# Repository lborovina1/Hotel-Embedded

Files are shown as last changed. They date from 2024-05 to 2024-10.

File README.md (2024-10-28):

# Hotel Management Embedded Systems Project

## Overview
This repository contains the implementation of an embedded systems project focused on developing a hotel management system. The project incorporates several essential components, including RFID programming for hotel room access, servo motor-controlled ramps, a user interface for programming RFID cards, and a gas detection alarm system. This project is part of the **Embedded Systems** course at the **Faculty of Electrical Engineering** at the **University of Sarajevo**.

Team members: Borovina Lamija, Jozić Ivona, Kurtović Esma and Muslić Ismar. </br>
Video demonstration: https://youtu.be/YYLt_LLE6pE </br>

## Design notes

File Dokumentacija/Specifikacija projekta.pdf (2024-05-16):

Specifikacija projekta na kursu Ugradbeni sistemi

Tema projekta: Hotel

Članovi tima: Borovina Lamija

Jozić Ivona

Kurtović Esma

Muslić Ismar

Specifikacija projekta:

U sklopu našeg projekta je planirana implementacija pojedinih funkcionalnosti koje se vežu za funkcioniranje hotela. Zamišljena je implementacija tri konkretne funkcionalnosti, koje se objedinjuju u jednu cjelinu. Planirane funkcionalnosti su:

1) Dodjela RFID kartica kao ključeva za sobe – RFID RC522 čitač i kartice
Ova funkcionalnost je zamišljena na način da se na recepciji hotela vrši povezivanje određene kartice i sobe. Za unošenje broja sobe se namjerava koristiti matrična tastatura, a unos će se prikazati na sedam segmentnom displeju.
Pri ulasku u sobu se očitava kartica, a za signalizaciju validnosti će biti korištene LED diode, pri čemu zelena svjetlost signalizira ispravnost, tj. da se u sobu može ući sa skeniranom karticom, dok crvena svjetlost signalizira neispravnost.
2) Ulazna rampa – servomotor i MQTT protokol komunikacije
Ova funkcionalnost je zamišljena kao simulacija rada parking rampe, koja će u demonstraciji biti predstavljena u vidu makete. Gosti hotela prilikom prijave u hotel dobivaju šifru klijenta za korištenje MQTT aplikacije.
Servomotor služi za podizanje rampe, a rad motora bi bio kontroliran kroz MQTT aplikaciju, te bi se pritiskom na dugme u aplikaciji aktivirao i podizao rampu.
3) Protupožarni alarm – MQ5 senzor i piezoelektrični zvučnik
Korištenjem MQ5 senzora za detekciju zapaljivih plinova je moguće detektovati prisustvo štetnih plinova, odnosno požara, te bi isti bio implementiran na način da prilikom detekcije nestandardnog sastava zraka, pokreće zvuk alarma koji bi bio se oglašavao kroz zvučnik. Ovo će predstavljati svojevrstan protupožarni alarm koji je prisutan u okviru svake hotelske sobe.

Razvojni sistem:

Zamišljeni sistem je planiran za implementaciju na Raspberry Pi Pico mikrokontroleru, s obzirom na dostupni broj pinova, kao i sadržavanje WiFi modula.

Komponente koje će biti korištene:

Naziv komponente:
RFID RC522 čitač
RFID kartice
Matrična tastatura
Četverocifreni sedam segmentni displej LED diode
Servomotor
MQ5 senzor za detekciju zapaljivih plinova Piezoelektrični zvučnik

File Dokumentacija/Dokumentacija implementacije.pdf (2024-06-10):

## Dokumentacija implementacije

Za potrebe projekta korištena su dva mikrokontrolera:

- Raspberry Pi Pico (spojena 2 RFID čitača, matrična tastatura i LCD displej)
- ESP8266 (spojen servomotor za rampu).

Planirane funkcionalnosti smo implementirali na sljedeći način:

1) Uvezivanje kartice s brojem sobe na recepciji
a. Unos broja sobe

Unos se započinje pritiskom na taster button. Za unos broja sobe se koristi matrična tastatura, a prilikom unosa informativne poruke se prikazuju na LCD displeju. Za potrebe obrade unosa se koriste klase Tastatura, pomoću koje se bilježi unos, te TastController, koji sadrži instancu klase Tastatura i vraća odgovarajuće vrijednosti u ovisnosti od validnosti unosa.

Očitavanje unosa s tastature je realizovano na sljedeći način:

- Zasebni redovi (u kodu rows, deklarisani kao digitalni izlazi) se pomoću Timer-a periodično pale. Trenutno aktivni red (sačuvan u varijabli currentRow) se tako mijenja svakih 50ms. Timer se inicijalizira pritiskom na gore navedeni button, u sklopu funkcije ocitaj():

self.timer=Timer(period=50, mode=Timer.PERIODIC, callback=self.rowFun)

- Na pin-ove za kolone (u kodu cols, deklarisane kao digitalni ulazi) su postavljeni hardverski interrupt-i, čija je callback funkcija colPress():

for i in range(4):
self.cols[i].irq(handler = self.colPress, trigger = Pin.IRQ_RISING)
- U okviru iste, nakon debouncing-a, se u varijablu currentCol pohranjuje broj pritisnute kolone.

Zatim se na osnovu vrijednosti currentRow i currentCol određuje pritisnuti taster, te akcija koju je potrebno izvršiti. Kao signalizacija neispravnog unosa ili potvrde se koriste bool varijable pogresanUnos i potvrdjeno. Unos se obrađuje na sljedeći način:

- Za pritisnute tastere 'A', 'B', 'D' i '*' se unos završava deinicijalizacijom timer-a i varijabla pogresanUnos postavlja na True.
- Pritiskom na taster '#' se potvrđuje četverocifreni unos te varijabla potvrdjeno postavlja na True. U slučaju da je '#' pritisnut prije nego što su unesene 4 cifre, unos nije validan te se ponovno pogresanUnos postavlja na True. U oba slučaja se unos završava deinicijalizacijom timer-a.
- Ukoliko je pritisnut taster 'C', briše se posljednji uneseni karakter.
- Tasteri s ciframa od '0' do '9' se smatraju validnim unosom, izuzev u situaciji kada se dotadašnji unos već sastoji od 4 cifre, jer se prelazi maksimalna dozvoljena veličina.

Ukoliko je unos ispravan, cifra se dodaje na string

self.string += self.matrica[self.currentRow][self.currentCol]

koji se ispisuje na displej

self.lcd.clear()
self.lcd.putstr(self.string).

U okviru metode getUnos() klase TastController, a koja se koristi za dobivanje unosa s tastature, se vraćaju odgovarajuće vrijednosti. Povratna vrijednost -1 označava neispravan unos (u slučaju da je pogresanUnos postavljen na True), a uneseni string označava ispravan unos (u slučaju da je potvrdjeno postavljeno na True).

b. Uvezivanje unesene sobe i RFID kartice prislonjene čitaču

Nakon što je završen unos pomoću matrične tastature, mogu nastupiti dva slučaja. Ukoliko je unos neispravan, pomoću LCD displeja se korisniku signalizira greška, te on ima opciju da ponovno započne unos pritiskom na button. U slučaju kada je unos broja sobe ispravan prelazi se na konfiguraciju, tj. uvezivanje unesene sobe s RFID karticom kojom se želi omogućiti ulazak u nju. Najprije se korisniku na displeju ispisuje poruka da RFID čitaču reader1 prinese karticu koja se želi uvezati sa sobom, te se očitava njegovo stanje.

(stat1, tag_type1) = reader1.request(reader1.REQIDL)

Kada se prinese kartica koja se želi konfigurisati, čita se njen ID

(stat, uid) = reader1.SelectTagSN()
card = int.from_bytes(bytes(uid),"little", False)

i u mapi karticeISobe se unesenoj sobi pridružuje vrijednost prislonjene kartice

karticeISobe[int(soba)] = card.

2) Pristup sobi pomoću kartice i RFID čitača

Čitanjem vrijednosti iz mape karticeISobe pri pokušaju ulaska u sobe se vrši provjera da li je dozvoljen pristup prislonjenom karticom. Ova funkcionalnost je demonstrirana pomoću RFID čitača reader2, koji predstavlja čitač za sobu 1000. Naime, nakon što se na recepciji na prethodno opisani način uveže soba 1000 s određenom karticom čiji se ID pohranjuje u mapu, prilikom prislanjanja kartice čitaču reader2, njen ID se poredi s vrijednošću u mapi.

if karticeISobe[1000] == card

Ukoliko su ove vrijednosti jednake, paljenjem zelene LED se signalizira da je kartica ispravna i njom se može pristupiti sobi. U suprotnom, paljenjem crvene LED se signalizira da prislonjena kartica nije povezana sa sobom kojom se pristupa, te ulazak u nju nije moguć.

3) Povezivanje i kontrola parking – rampe

Kontrola parking rampe je implementirana koristeći MQTT komunikacijski protokol. Na uređaju ESP8266 je inicijalizirana konekcija na WiFi koristeći SSID i password lokalne WiFi mreže, nakon čega se MQTT klijent može uspješno povezati na cloud brokera. Istovremeno je na kontrolnom uređaju (Android smartphone) podešena „MQTT Dash“ aplikacija sa podešenim opcijama za sve funkcionalnosti sistema. Moguće je jednim tasterom aktivirati rampu, te imati uvid u trenutno stanje sistema i konekcije, kao i stanje semafora (zeleno i crveno svjetlo).

Pozivom metode

client.subscribe("USprojekat/Servo", [](const String & payload)

podešava se supskripcija na temu „USprojekat/Servo“ koja se koristi za kontrolu servo motora, odnosno same rampe. Sve ostale teme se koriste samo za publishing statusnih poruka o sistemu, tako da za njih nije ni potrebna supskripcija.

Lambda funkcija koja je proslijeđena kao parametar metodi subscribe() se bavi svim funkcijama vezanim za kontroliranje same rampe. U slučaju da je sa korisničke strane na temi registrovana poruka „1“, za aktiviranje rampe, najprije se publish-aju poruke o stanju LED dioda na odgovarajuće teme, a zatim se i podiže sama rampa podešenjem ugla otklona servo motora.

| int pos = 0;
for(pos; pos <= 180; pos += 5) servo.write(pos);

Na isti način se rampa ponovno i spušta nakon čekanja od 10s da bi automobil mogao da prođe. Tim želi naglasiti da je kvalitetnije rješenje implementirati u sklopu rampe i ultrazvučni mjerač udaljenosti ili IR blaster i reciever sa suprotnih strana kako bi sistem „znao“ kada je automobil ispod rampe. Time bi se izbjeglo da rampa udari u automobil u slučaju da za 10s on ne prođe ispod iste. Nažalost, u sklopu ovog projekta nije bilo dovoljno vremena za takvu implementaciju.
Statusne poruke o stanju rampe se pravovremeno šalju na svoje odgovarajuće teme, a također se i na serijski port šalju iste poruke, kako bi se uz pomoć monitora serijske veze uvidjelo funkcioniranje mikrokontrolera i olakšalo eventualno servisiranje, odnosno debugging. Poruke koje se ispisuju su u formatu:

Serial.println("Podizem rampu...");
Serial.println("Rampa podignuta!"); Serial.println("Spustam rampu...");
Serial.println("Rampa spustena.");

Iste statusne poruke se šalju i na odgovarajuće teme metodom publish() kako bi se i na korisničkoj strani mogle vidjeti u okviru MQTT Dash aplikacije.

4) Smoke alarm (MQ5 senzor zapaljivih plinova)

Koristeći MQ5 senzor zapaljivih gasova i aktivni buzzer s radnim naponom od 5V, realiziran je jednostavan alarm za dim, koji svaka hotelska soba posjeduje.

Kompletan sklop je zalemljen na perfboard i odvojen od sistema mikrokontrolera, te tako radi potpuno automatski. S obzirom na to da MQ5 senzor daje logičko 0 na digitalnom izlazu kada je plin detektovan, a logičko 1 onda kada plina nema, potrebno je bilo napraviti inverter signala, što je realizirano uz pomoć dva NPN tranzistora, konkretnije, BC547. Također je paralelno sa digitalnim izlazom i GND spojen kondenzator kapaciteta 470 µF, kako bi se osiguralo da nekonzistentne promjene stanja na digitalnom izlazu (stanja između 0 i 5V) budu zanemarena, te da se tranzistorima baza ispravno otvara. Prvi tranzistor funkcionira kao inverter signala, te je njegov kolektor direktno prespojen sa bazom drugog tranzistora, dok je istom emiter spojen na GND. Tako se osigurava da na bazu drugog tranzistora dovodimo struju samo onda kada je baza prvog tranzistora zatvorena, odnosno kada je na digitalnom izlazu 0V. Drugi tranzistor potom, prilikom otvaranja baze, propušta napon od 5V na aktivni piezoelektrični buzzer.

Detaljna shema spajanja, kao i shema električnog kruga, je data u prilogu.

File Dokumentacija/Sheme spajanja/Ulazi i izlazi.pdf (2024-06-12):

## Ulazi i izlazi

## Raspberry Pi Pico

Digitalni izlazi | Digitalni ulazi
Pin(16, Pin.OUT) (red 1) | Pin(0, Pin.IN, Pin.PULL_DOWN) (button)
Pin(17, Pin.OUT) (red 2) | Pin(20, Pin.IN, Pin.PULL_DOWN) (kol 1)
Pin(18, Pin.OUT) (red 3) | Pin(21, Pin.IN, Pin.PULL_DOWN) (kol 2)
Pin(19, Pin.OUT) (red 4) | Pin(22, Pin.IN, Pin.PULL_DOWN) (kol 3)
Pin(7, Pin.OUT) (crvena LED) | Pin(26, Pin.IN, Pin.PULL_DOWN) (kol 4)
Pin(6, Pin.OUT) (zelena LED)
SPI izlazi | SPI ulazi
sck=Pin(2) (reader1 clock) | miso=Pin(4) (reader1 MISO)
mosi=Pin(3) (reader1 MOSI) | miso=Pin(12) (reader2 MISO)

### cs=Pin(1) (reader1 CS) rst=Pin(5) (reader1 RST) sck=Pin(10) (reader2 clock) mosi=Pin(11) (reader2 MOSI) cs=Pin(9) (reader2 CS) rst=Pin(13) (reader2 RST)

I2C izlazi | I2C ulazi
sda=Pin(14) (I2C data)
scl=Pin(15) (I2C clock)

## ESP8266

## Digitalni izlazi

SERVO (D4) | (kontrola servo motora)
LED_RED (D2) | (crvena LED)
LED_GREEN (D1) | (zelena LED)

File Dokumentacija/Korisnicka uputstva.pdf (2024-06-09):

### Korisnička uputstva

Korištenje sistema projektovanog u sklopu ovog projekta je zapravo veoma jednostavno unatoč njegovom nešto obimnijem sadržaju.

U sklopu sistema postoji nekoliko funkcionalnosti čiji će način korištenja u nastavku biti detaljno objašnjen. Svi potrebni kodovi i biblioteke su već spremljeni na razvojne sisteme, tako da je za pokretanje svih funkcionalnosti neophodno samo priključivanje napajanja na struju korištenjem odgovarajućeg adaptera.

U nastavku uputstva za korištenje svake od funkcionalnosti sadržanih u sklopu projekta:

1) Uvezivanje kartice sa brojem sobe na recepciji

Za pokretanje ovog modula rada potrebno je da pritisnete taster, nakon čega će se na LCD ekranu ispisivati sva uputstva.
Prvo je potrebno da unesete odgovarajući broj sobe korištenjem matrične tastature, gdje se zahtijeva da se unesu 4 cifre. U slučaju da sa tastature unesete karaktere A, B, D ili *, na ekranu će se ispisati poruka o grešci te će biti neophodno da ponovite unos. Karakter C možete koristiti u slučaju greške, za brisanje unosa (jedan pritisak će ukloniti jednu unesenu cifru). Nakon što unesete 4 cifre, trebate pritisnuti karakter # na matričnoj tastaturi kako bi vaš unos bio potvrđen.
Na LCD ekranu će biti ispisana poruka o uspješnom unosu nakon čega imate 2s da prislonite odgovarajuću karticu na RFID. Za povezivanje soba i kartica koristi se tamniji RFID čitač.
Pošto isteknu 2s, na LCD ekranu će biti ispisana poruka „Uklonite karticu“ koja signalizira kraj povezivanja. Kartica je sada spremna za korištenje pri ulasku u sobu.
2) Ulazak u sobe

Za ulaz u sobe koristiti ranije povezanu karticu i nju skenirate RFID čitačem (ovaj put je u pitanju svjetliji RFID čitač). Nakon što prislonite karticu, ukoliko je ona odgovarajuća, upalit će se zelena LED dioda koja signalizira da je ulaz u sobu moguć. Ukoliko dođe do paljenja crvene LED diode, došlo je do greške, koja je uzrokovana očitavanjem pogrešne kartice.

3) Parking rampa

Za podizanje rampe se koristi MQTT komunikacijski protokol.
Naime, potrebno je posjedovati MQTT Dash aplikaciju, ili neku sličnu njoj, te postavke za odgovarajućeg klijenta. Ako sve to posjedujete, parking rampom upravljate veoma jednostavno. Kada se približite rampi, potrebno je da u aplikaciji pritisnete taster koji će podići rampu, nakon čega ona ostaje podignuta 10s i zatim se automatski spušta.

Pored rampe, u sistem su ugrađene i dvije LED diode, crvena i zelena, čije su uloge dodatna signalizacija. Sve dok je upaljena crvena dioda, rampa će biti spuštena, a nakon pritiska na odgovarajući taster, pali se zelena dioda i započinje podizanje rampe.

4) Protupožarni alarm

Senzor za protupožarni alarm je kalibriran na način da će u slučaju prisustva plina ili CO2 gasa u zraku aktivirati alarm. Senzor je priključen na napajanje, tako da je i za njegovu aktivaciju dovoljno samo priključiti sistem na izvor energije, a sve ostalo će se odvijati po automatizmu.

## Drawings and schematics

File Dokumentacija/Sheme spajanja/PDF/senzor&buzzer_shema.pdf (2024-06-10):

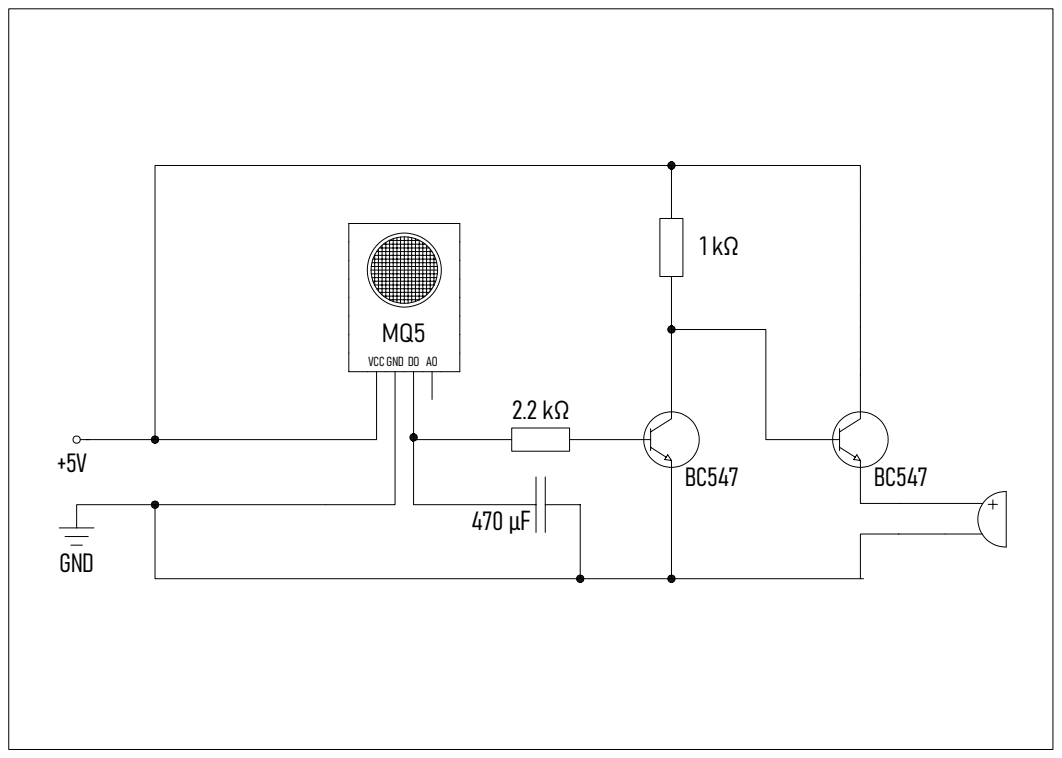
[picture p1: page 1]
MQ5 VCC GND DO AO; BC547 +5V GND

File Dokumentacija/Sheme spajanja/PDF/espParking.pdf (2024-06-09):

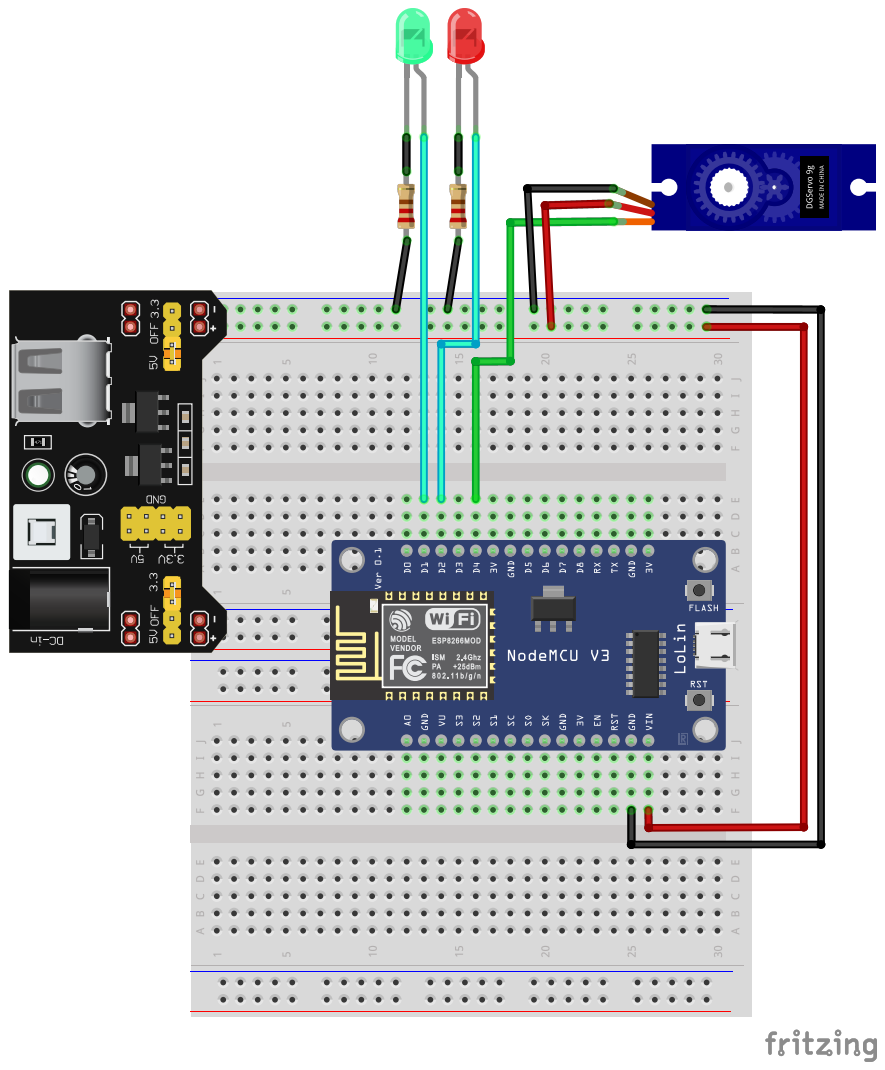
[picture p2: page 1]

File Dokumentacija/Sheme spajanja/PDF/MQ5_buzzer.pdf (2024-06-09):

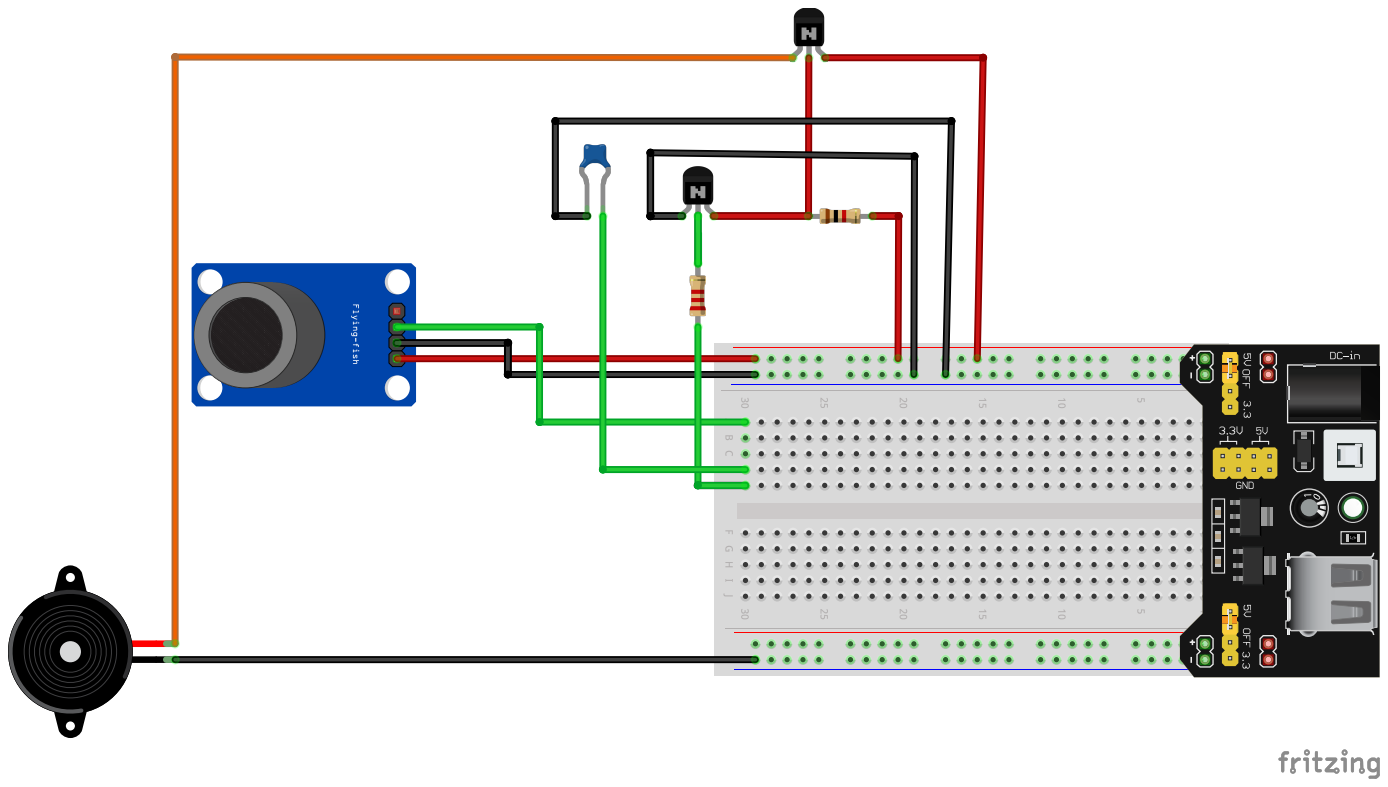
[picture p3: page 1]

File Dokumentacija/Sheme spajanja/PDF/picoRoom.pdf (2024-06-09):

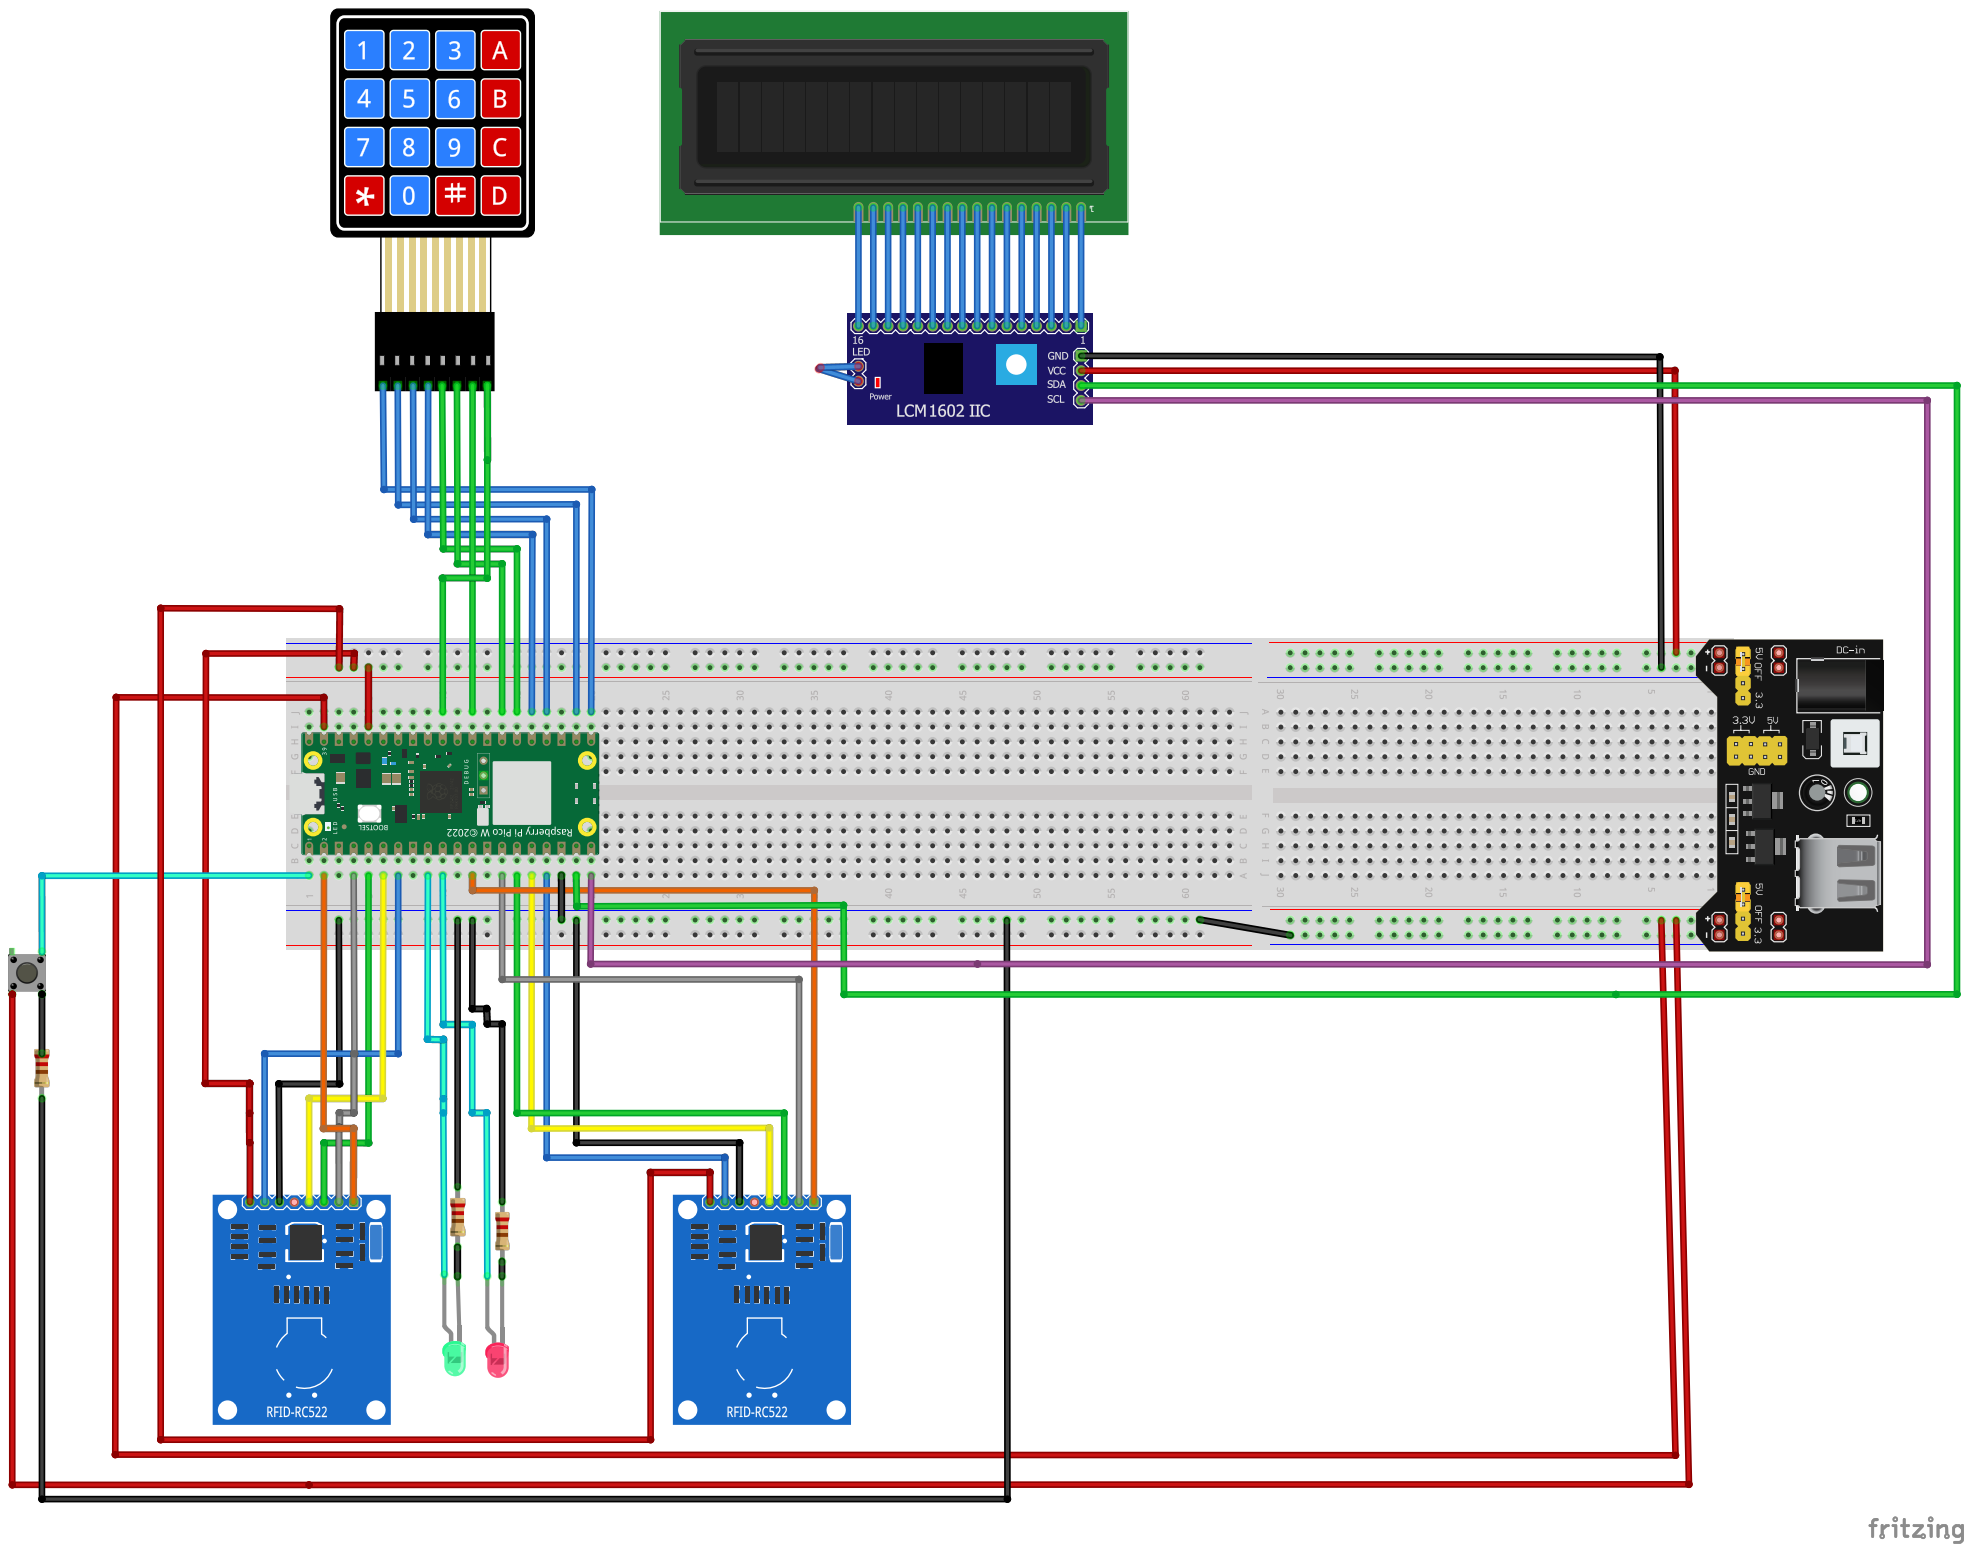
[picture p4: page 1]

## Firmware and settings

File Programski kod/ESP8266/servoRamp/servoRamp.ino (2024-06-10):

#include <Servo.h>
#include "EspMQTTClient.h"

#define LED_RED D2
#define LED_GREEN D1
#define SERVO D4

Servo servo;

EspMQTTClient client(
  "Asterix_WLAN",       // WiFi SSID
  "123A456d78",         // WiFi Password
  "broker.hivemq.com",  // MQTT Broker server ip
  "TestClient",         // Klijentsko ime, identifikator uredjaja 
  1883                  // MQTT port, default-ni 1883
);

// Ova funkcija se poziva kada je konekcija uspostavljena (Wifi i MQTT)
void onConnectionEstablished() {
  LEDSignal();
  Serial.println("WiFi Connected");
  client.publish("USprojekat/Konekcija", "Device Online", true);
  client.publish("USprojekat/ZelenoSvjetlo", "0");
  client.publish("USprojekat/CrvenoSvjetlo", "1");
  client.publish("USprojekat/Servo", "0");
  
  // Subscribe na temu "USprojekat/Servo" 
  client.subscribe("USprojekat/Servo", 
    [](const String & payload) {
      Serial.println(payload);

      if(payload == "1") {
        // Pali se zelena LED za signalizaciju dizanja rampe 
        client.publish("USprojekat/ZelenoSvjetlo", "1");
        client.publish("USprojekat/CrvenoSvjetlo", "0");
        digitalWrite(LED_RED, LOW);
        digitalWrite(LED_GREEN, HIGH);

        // Rampa se dize
        Serial.println("Podizem rampu...");
        client.publish("USprojekat/Info", "Podizem rampu...");
        int pos = 0;
        for(pos; pos <= 180; pos += 5) // Rampa se postepeno dize, povecanjem ugla otklona
          servo.write(pos);

        // Cekanje 10 sekundi da automobil prodje 
        Serial.println("Rampa podignuta!");
        client.publish("USprojekat/Info", "Rampa podignuta!");
        delay(10000);

        // Pali se crvena LED za signalizaciju spustanja rampe
        client.publish("USprojekat/ZelenoSvjetlo", "0");
        client.publish("USprojekat/CrvenoSvjetlo", "1");
        digitalWrite(LED_RED, HIGH);
        digitalWrite(LED_GREEN, LOW);

        // Rampa se spusta
        Serial.println("Spustam rampu...");
        client.publish("USprojekat/Info", "Spustam rampu...");
        for(pos = 180; pos >= 0; pos -= 3)  // Rampa se postepeno spusta, smanjenjem ugla otklona
          servo.write(pos); 
        
        Serial.println("Rampa spustena.");
        client.publish("USprojekat/Info", "Rampa spustena.");
        client.publish("USprojekat/Servo", "0");    
      }
    });
}

// Funkcija koja se koristi kao signalizator uspostavljene konekcije (blicanje ugradjene LED)
void LEDSignal() {
  digitalWrite(LED_BUILTIN, HIGH);  
  delay(100);                      
  digitalWrite(LED_BUILTIN, LOW);   
  delay(100);   
  digitalWrite(LED_BUILTIN, HIGH);  
  delay(100);                      
  digitalWrite(LED_BUILTIN, LOW);   
  delay(100);   
  digitalWrite(LED_BUILTIN, HIGH);  
  delay(100);                      
  digitalWrite(LED_BUILTIN, LOW);   
  delay(100);   
}

void setup() {
  Serial.begin(115200);
  
  client.enableLastWillMessage("USprojekat/Konekcija", "Device Offline", true);  
  client.enableMQTTPersistence();

  servo.attach(SERVO);            // Povezivanje motora sa mikrokontrolerom preko macro-a SERVO
  servo.write(0);                 // Postavljanje inicijalne pozicije rampe
  pinMode(LED_RED, OUTPUT);       // Inicijalizacija crvene LED 
  pinMode(LED_GREEN, OUTPUT);     // Inicijalizacija zelene LED

  // Na pocetku crvena LED upaljena, a zelena ugasena zato sto je rampa spustena
  digitalWrite(LED_RED, HIGH);
  digitalWrite(LED_GREEN, LOW);
}

void loop() {
  // Provjerava se prijem nove poruke svakih 250ms
  client.loop();
  delay(250);
}

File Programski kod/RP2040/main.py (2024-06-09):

from machine import Pin, Timer,I2C
from mfrc522 import MFRC522
from time import sleep, ticks_ms, ticks_diff
from tastatura import Tastatura, TastController
from pico_i2c_lcd import I2cLcd

# Konstante za potrebe displeja
I2C_ADDR     = 63
I2C_NUM_ROWS = 2
I2C_NUM_COLS = 16

# Inicijalizacija dva RFID citaca
reader1 = MFRC522(spi_id=0,sck=2,miso=4,mosi=3,cs=1,rst=5) 			# Recepcija - konfiguracija sobe
reader2 = MFRC522(spi_id=1,sck=10,miso=12,mosi=11,cs=9,rst=13)		# Pri ulasku u sobu

soba = 0						# Uneseni broj sobe
tastatura = TastController()
debounce = ticks_ms()
       
button = Pin(0, Pin.IN)			# Pritiskom na button se zapocinje unos na tastaturi

# LED koje signaliziraju ispravnost ocitane kartice pri ulasku u sobu
red = Pin(7, Pin.OUT)
green = Pin(6, Pin.OUT)
red.value(0)
green.value(0)

# Inicijalizacija displeja
i2c = I2C(1, sda=Pin(14), scl=Pin(15), freq=400000)
lcd = I2cLcd(i2c, I2C_ADDR, I2C_NUM_ROWS, I2C_NUM_COLS)

# Mapa u kojoj su pohranjeni parovi soba i odgovarajucih kartica
karticeISobe = {
  1000: 0,
  1001: 0,
  1002: 0,
  2000: 0,
  2001: 0,
  2002: 0,
  3000: 0,
  3001: 0,
  3002: 0
}

# Funkcija koja se poziva pritiskom na button, cime se zapocinje unos broja sobe
def unosSobe():
    global soba, sobaUnesena, debounce, tastatura

    if ticks_diff(ticks_ms(), debounce) < 300: 			# Debouncing
        return
    else:
        debounce = ticks_ms()

    soba = tastatura.getUnos()

while True:
    red(0)
    green(0)
    
    # Pritisnut taster - konfiguracija sobe
    if button.value():
        unosSobe() 
        lcd.clear()
        if soba == -1:							# Ukoliko je iz funkcije za ocitanje unosa vraceno -1, unos nije validan
            lcd.putstr("Pogresan unos!")
            sleep(2)
            lcd.clear()
            lcd.putstr("Kliknite taster\ni unesite opet")
        else:									# Validan unos, zapocinje se konfiguracija sobe
            lcd.putstr("Unijeli ste: \n" + soba)  
            sleep(2)
            lcd.clear()
            lcd.putstr("Prislonite\nkarticu: \n") 
            reader1.init()
            stat1 = False

            sleep(2)
            lcd.clear()
            (stat1, tag_type1) = reader1.request(reader1.REQIDL)		# Ocitava se da li je prislonjena kartica na RFID citac 
            
            if stat1 == reader1.OK:
                (stat, uid) = reader1.SelectTagSN()						# Ocitava se ID prislonjene kartice
                if stat == reader1.OK:
                    card = int.from_bytes(bytes(uid),"little",False) 
                    karticeISobe[int(soba)] = card						# Unesenoj sobi se dodjeljuje ID prislonjene kartice
                    
                    lcd.putstr("Povezano!")
                    sleep(1)
                    lcd.clear()
                    lcd.putstr("Uklonite\nkarticu!")
                    sleep(1)
                    lcd.clear()
    
    # Nije pritisnut taster - ispituje se da li se pokusava pristupiti sobi
    else:
        reader2.init()
        (stat2, tag_type2) = reader2.request(reader2.REQIDL)			# Ocitava se da li je prislonjena kartica na RFID citac 
   
        if stat2 == reader2.OK:
            (stat, uid) = reader2.SelectTagSN()							# Ocitava se ID prislonjene kartice
            if stat == reader2.OK:
                card = int.from_bytes(bytes(uid),"little",False)

                if karticeISobe[1000] == card:							# Ako je prislonjena kartica odgovarajuca, pali se zelena LED
                    red.value(0)
                    green.value(1)
                    sleep(2)
                    green.value(0)
                else:													# Prislonjena kartica nije odgovarajuca, pali se crvena LED
                    red.value(1)
                    green.value(0)
                    sleep(2)
                    red.value(0)
    sleep(0.1)

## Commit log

2024-05-28 MQTT functional for servo control + extras
2024-06-01 Fixed MQTT disconnection on ESP8266 + room LED behavior on Pico W
    [main.py, servoRamp.ino]
2024-06-09 Sheme spajanja
    [MQ5_buzzer.fzz, espParking.fzz, picoRoom.fzz]
2024-06-10 sitna prepravka u servoRamp + senzor&buzzer shema
    [servoRamp.ino]
2024-06-10 reorganized the repo
    [MQ5_buzzer.fzz, espParking.fzz, picoRoom.fzz]
2024-06-10 final reorganization and renaming
    [MQ5_buzzer.fzz, espParking.fzz, picoRoom.fzz]
2024-06-10 removed redundant files
    [MQ5_buzzer.fzz, espParking.fzz, picoRoom.fzz]
2024-06-11 Ulazi i izlazi za Raspberry Pi Pico
